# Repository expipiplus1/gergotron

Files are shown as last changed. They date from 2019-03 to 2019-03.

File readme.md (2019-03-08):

#

## Pins:

### PS/2:

TXB0104: http://www.ti.com/lit/ds/symlink/txb0104.pdf

| PS/2 | TXB0104 | P3 | Arduino | DE10-nano | Notes |
|---|---|----|---|---|---|
| J1 clock | channel 1 | 5  | IO13 | AH12 | |
| J1 data  | channel 2 | 2  | SDA | AH9 | |
| J2 clock | channel 3 | 7  | IO11 | AG16 | |
| J2 data  | channel 4 | 6  | IO12 | AH11 | |
| | OE | 1  | SCL | AG11 | 4.7kΩ pull-down |

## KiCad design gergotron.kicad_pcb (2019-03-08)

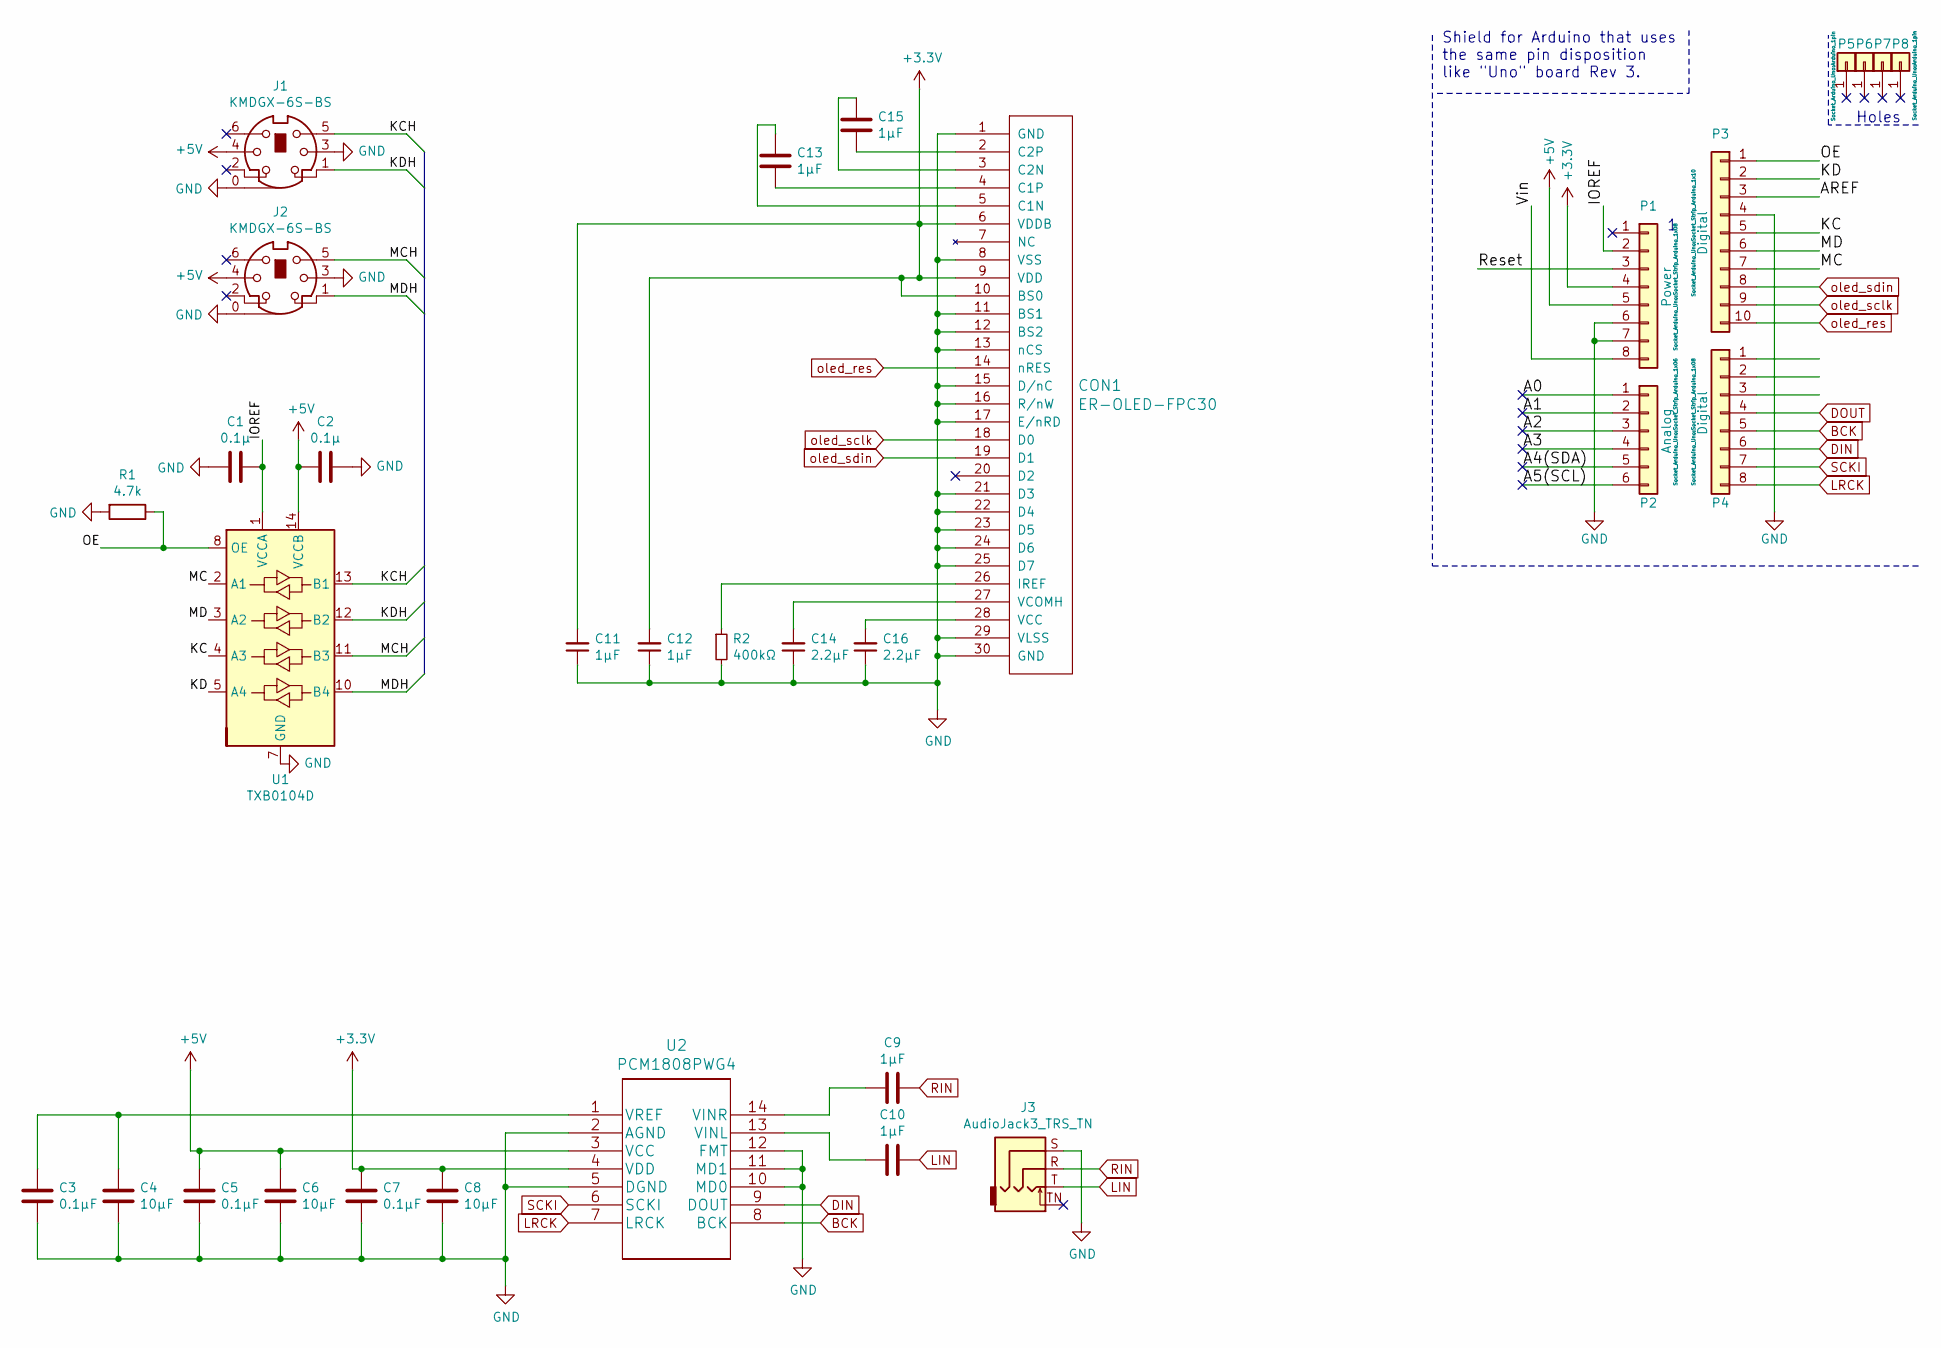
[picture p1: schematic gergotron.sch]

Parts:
C1, C2: 0.1μ; C_0603_1608Metric
C3, C5, C7: 0.1μF; C_0603_1608Metric
C4, C6, C8: 10μF; C_0805_2012Metric
C9, C10, C11, C12, C13, C15: 1μF; C_0603_1608Metric
C14, C16: 2.2μF; C_0603_1608Metric
CON1: ER-OLED-FPC30; er-oled-fpc30-flipped
J1, J2: KMDGX-6S-BS; kmdgx-6s-bs
J3: AudioJack3_TRS_TN; sj-352x-smt
P1: Power; Socket_Strip_Arduino_1x08
P2: Analog; Socket_Strip_Arduino_1x06
P3: Digital; Socket_Strip_Arduino_1x10
P4: Digital; Socket_Strip_Arduino_1x08
P5, P6, P7, P8: CONN_01X01; Arduino_1pin
R1: 4.7k; R_0603_1608Metric
R2: 400kΩ; R_0603_1608Metric
U1: TXB0104D; SOIC-14_3.9x8.7mm_P1.27mm
U2: PCM1808PWG4

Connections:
+3V3: C7.1, C8.1, C11.2, C12.2, CON1.6 (VDDB), CON1.9 (VDD), CON1.10 (BS0), P1.4, U2.4 (VDD)
+5V: C2.1, C5.1, C6.1, J1.4, J2.4, P1.5, U1.14 (VCCB), U2.3 (VCC)
/A0: P2.1
/A1: P2.2
/A2: P2.3
/A3: P2.4
/A4(SDA): P2.5
/A5(SCL): P2.6
/AREF: P3.3
/IOREF: C1.2, P1.2, U1.1 (VCCA)
/KC: P3.5, U1.4 (A3)
/KCH: J1.5, U1.13 (B1)
/KD: P3.2, U1.5 (A4)
/KDH: J1.1, U1.12 (B2)
/MC: P3.7, U1.2 (A1)
/MCH: J2.5, U1.11 (B3)
/MD: P3.6, U1.3 (A2)
/MDH: J2.1, U1.10 (B4)
/OE: P3.1, R1.1, U1.8 (OE)
/Reset: P1.3
/Vin: P1.8
BCK: P4.5, U2.8 (BCK)
DIN: P4.6, U2.9 (DOUT)
DOUT: P4.4
GND: C1.1, C2.2, C3.2, C4.2, C5.2, C6.2, C7.2, C8.2, C11.1, C12.1, C14.1, C16.1, CON1.1 (GND), CON1.8 (VSS), CON1.11 (BS1), CON1.12 (BS2), CON1.13 (nCS), CON1.15 (D/nC), CON1.16 (R/nW), CON1.17 (E/nRD), CON1.21 (D3), CON1.22 (D4), CON1.23 (D5), CON1.24 (D6), CON1.25 (D7), CON1.29 (VLSS), CON1.30 (GND), J1.0, J1.3, J2.0, J2.3, J3.S, P1.6, P1.7, P3.4, R1.2, R2.2, U1.7 (GND), U2.2 (AGND), U2.5 (DGND), U2.10 (MD0), U2.11 (MD1), U2.12 (FMT)
LIN: C10.2, J3.T
LRCK: P4.8, U2.7 (LRCK)
unnamed: C3.1, C4.1, U2.1 (VREF)
unnamed: C9.1, U2.14 (VINR)
unnamed: C10.1, U2.13 (VINL)
unnamed: C13.1, CON1.5 (C1N)
unnamed: C13.2, CON1.4 (C1P)
unnamed: C14.2, CON1.27 (VCOMH)
unnamed: C15.1, CON1.3 (C2N)
unnamed: C15.2, CON1.2 (C2P)
unnamed: C16.2, CON1.28 (VCC)
unnamed: CON1.26 (IREF), R2.1
RIN: C9.2, J3.R
SCKI: P4.7, U2.6 (SCKI)
oled_res: CON1.14 (nRES), P3.10
oled_sclk: CON1.18 (D0), P3.9
oled_sdin: CON1.19 (D1), P3.8

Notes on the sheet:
Holes
Shield for Arduino that uses the same pin disposition like "Uno" board Rev 3.

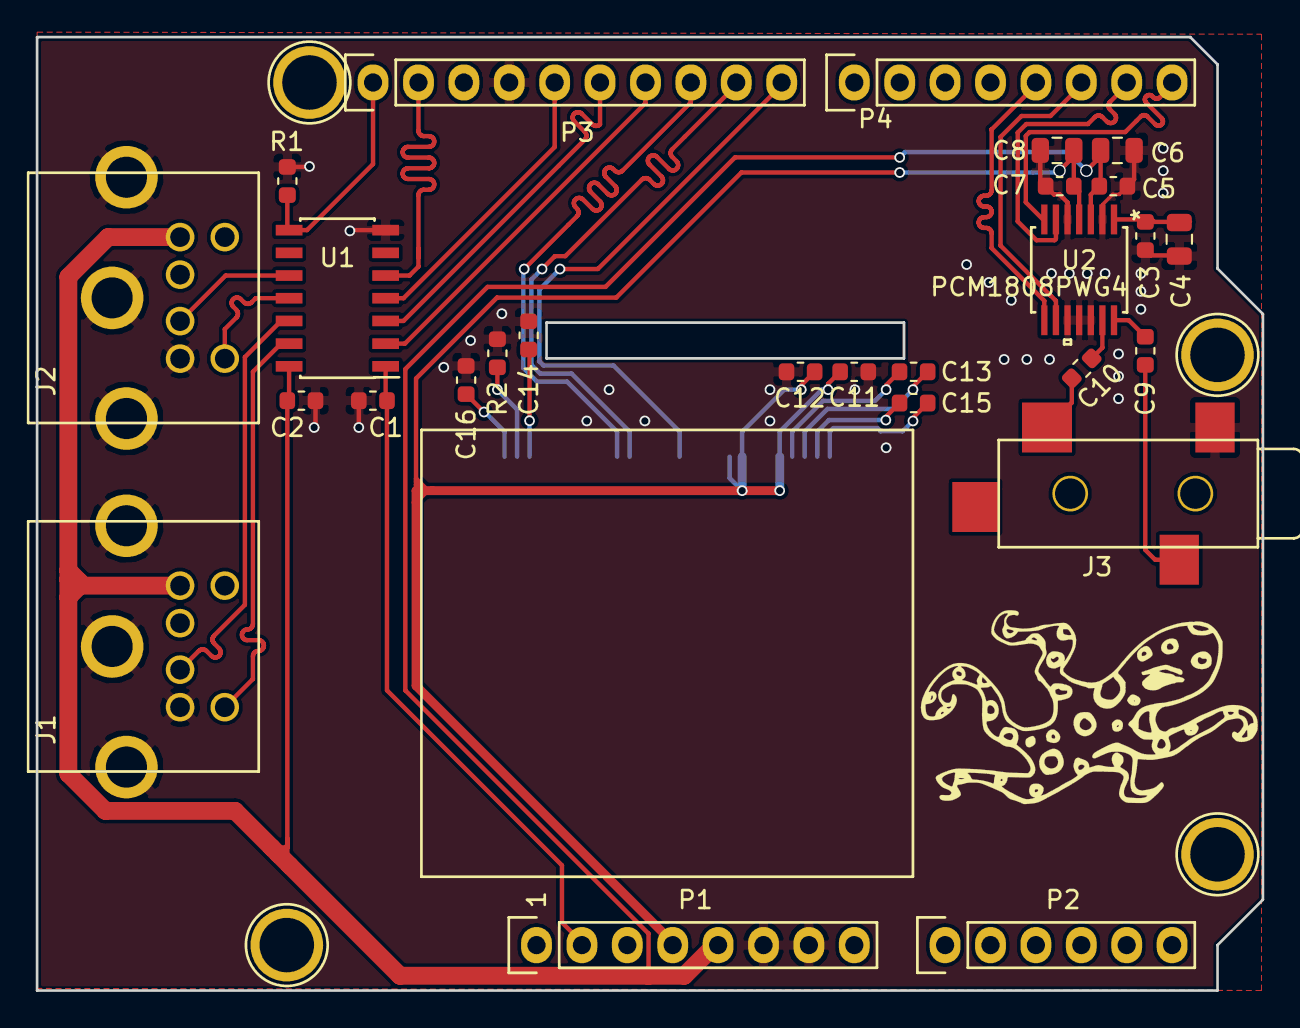
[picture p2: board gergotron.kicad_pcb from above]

Board: 2 copper layers, 68.6 x 53.3 mm, 32 parts (1 on the bottom side), 32 nets.

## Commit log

2018-11-15 initial commit, template project
    [gergotron.kicad_pcb, gergotron.sch]
2018-11-15 ps/2 done
    [gergotron.kicad_pcb, gergotron.sch]
2018-11-15 Add audio in
    [gergotron.kicad_pcb, gergotron.sch]
2018-11-17 Add oled display
    [gergotron.kicad_pcb, gergotron.sch]
2018-11-17 power to the oled
    [gergotron.kicad_pcb, gergotron.sch]
2018-11-19 Fiddle traces
    [gergotron.kicad_pcb]
2018-11-19 Tidy up schematic and connect unused data wires to gnd
    [gergotron.kicad_pcb, gergotron.sch]
2018-11-19 Start work on the DAC
    [gergotron.kicad_pcb, gergotron.sch]
2019-01-12 remove audio out
    [gergotron.kicad_pcb, gergotron.sch]
2019-01-14 Added octopus
    [gergotron.kicad_pcb]
2019-03-08 Octo on pcb
    [gergotron.kicad_pcb]

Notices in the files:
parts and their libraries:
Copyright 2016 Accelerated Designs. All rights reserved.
